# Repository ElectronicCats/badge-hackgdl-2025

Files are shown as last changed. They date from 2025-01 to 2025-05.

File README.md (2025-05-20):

# Badge HackGDL 2025

<p align="center">
    <a href="https://github.com/ElectronicCats/badge-hackgdl-2025/wiki">
        
    </a>
</p>

<p align=center>
    <a href="https://github.com/ElectronicCats/Minino/wiki">
        
    </a>
</p>

Welcome to the official repository of the Hack GDL 2025 event badge, developed by Electronic Cats. This portable device is designed to be interactive, educational, and hackable. It is based on the [Minino](https://github.com/ElectronicCats/Minino) platform, which uses ESP-IDF as the development environment and offers a modular system for creating BLE and Wi-Fi applications.

## Features:
- ESP32-S3
- Bluetooth Low Energy (BLE) + Wi-Fi
- USB-C for power and programming
- 4 x physical buttons for interaction
- 3 neopixel
- Integrated OLED Screen
- 3x AAA Battery Holder
- 1 x Buzzer
- Shitty Addon Connector
- Case
- Based on [Minino](https://github.com/ElectronicCats/Minino), with a modular architecture for multiple apps

## Included Applications:
These applications are ready-to-use and serve as a base for creating your own ideas during the event.
- Bluetooth (BLE) Applications
- Wi-Fi Applications
- Digital Tamagotchi

## Flashing Firmware:
Your badge should come with the latest firmware. If an update is required, this section of the wiki will explain how to flash your badge with the latest firmware. 

### Bootloader mode

To be able to flash your board, you will need to understand how to put it into bootloader mode. You just need to follow the sequence below:

* Press and hold the **BOOT** button
* Press and release the **RST** button
* Release the **BOOT** button

### ESP Tool (Web) update

1. Download the latest firmware from the [releases](https://github.com/ElectronicCats/badge-hackgdl-2025/releases) section.

2. Extract the downloaded file.

3. Open your web browser and go to [ESP Tool](https://espressif.github.io/esptool-js/).

4. Connect your badge to your computer using a USB cable and enter [bootloader mode](https://github.com/ElectronicCats/badge-hackgdl-2025/edit/main/README.md#bootloader-mode). 

5. Once on the page, in the baud rate, select 460800 and click on the “Connect” button.

6. You will see a pop-up window asking you to select the port where your badge is detected. Choose the one labeled “USB JTAG/serial debug unit.”

7. Once your badge is connected, the website will display the “Flash Address” field. Enter 0x0 in that field.

8. Click on “Select File” and look for the files in the unzipped folder. You must match the file and address according to the following table:

| Flash Address | File |
|---|---|
| 0x0 | HackGDL_2025.bin |

9. Once you have all the files, click on “Program.” Wait until the process ends, or you read the message “Leaving...” in the output console.

<p align=center>

</p>

10. When the program is finished, click on the “Disconnect” button.
11. Reset your HackGDL 2025 badge.

### Using the console

>[!IMPORTANT]
> [esptool.py](https://pypi.org/project/esptool/) is required.

To update your badge’s firmware, follow these steps:

1. Download the latest firmware from the [releases](https://github.com/ElectronicCats/badge-hackgdl-2025/releases).

3. Extract the downloaded file.

3. Open a terminal and navigate to the extracted folder. Make sure you see the HackGDL_2025.bin file.

4. Connect your badge to your computer using a USB cable and enter [bootloader mode](https://github.com/ElectronicCats/badge-hackgdl-2025/edit/main/README.md#bootloader-mode). Then check the port it is connected to.
    - **Windows**: Check it in the Device Manager under the Ports section.
    - **Linux**: check it with the `ls /dev/ttyUSB*` or `ls /dev/ttyACM*` command.
    - **macOS**: Check it with the `ls /dev/cu.usb*` command.

5. Run the following command to flash the firmware:

```python
python -m esptool --chip esp32s3 -b 460800 --before default_reset --after hard_reset write_flash --flash_mode dio --flash_size 4MB --flash_freq 80m 0x0 HackGDL_2025.bin
```

## Development Reference:

To compile, modify, or develop new applications for this badge, follow the official [Minino firmware development guide](https://github.com/ElectronicCats/Minino/tree/main/firmware).

> [!NOTE]  
> Although the Minino platform was designed for ESP32-C6, the HackGDL 2025 badge uses an ESP32-S3 as the main microcontroller. Make sure to configure the correct chip target in your development environment.

It includes:
ESP-IDF installation (v5.1.2)
Environment setup
Firmware compilation
Modular app structure
Flash and monitor commands

## FAQs
**Does the badge work out of the box?**

Yes. It comes with functional BLE and WiFi-based apps pre-installed.

**Can I develop my own app?**

Absolutely! Use Minino’s modular system and examples as a starting point.

**Where can I get help?**

Check the Minino wiki or open an issue [here](https://github.com/ElectronicCats/badge-hackgdl-2025/issues).

## Gratitude
Do you want to say thank you? Tag these companies on social networks and show them your badge, thanks to them, it is possible

- [ElectronicCats](https://electroniccats.com/)
- [HackGDL](https://hackgdl.net/)
- [Project TamaLib: A hardware-agnostic first-gen Tamagotchi emulation library](https://github.com/jcrona/tamalib)

## License

<a href="https://github.com/ElectronicCats">
    
</a>

Electronic Cats invests time and resources providing this open source design, please support Electronic Cats and open-source hardware by purchasing products from Electronic Cats!

Designed by Electronic Cats.

Firmware released under an GNU AGPL v3.0 license. See the LICENSE file for more information.

Hardware released under an CERN Open Hardware License v1.2. See the LICENSE_HARDWARE file for more information.

Electronic Cats is a registered trademark, please do not use if you sell these PCBs.

Nov 29 2022

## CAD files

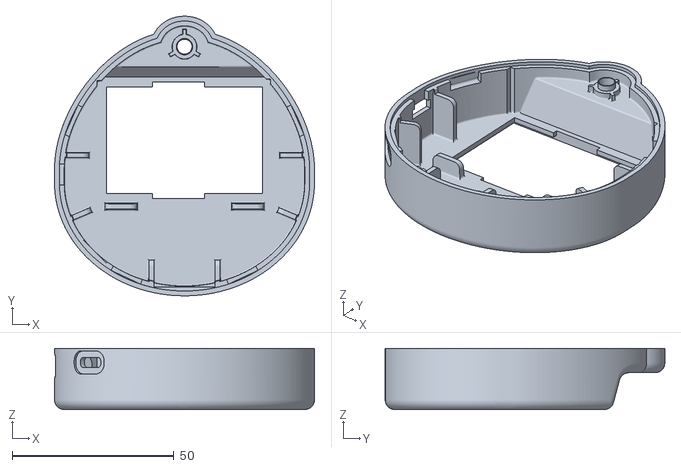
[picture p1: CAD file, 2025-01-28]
case/BOTTOM.stl
80.4 x 86.5 x 18.9

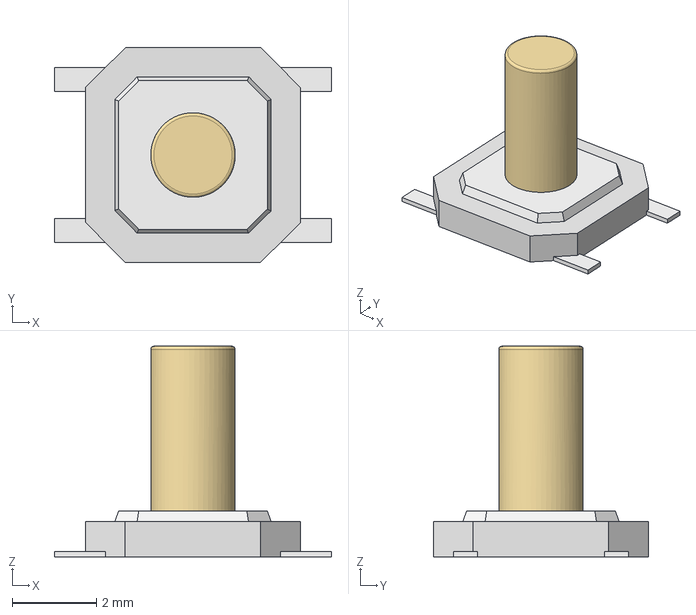
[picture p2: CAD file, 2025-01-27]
hardware/3dmodels/Tactal Switch - SMD (5mmx 5mmx5.0mm).stp
6.58 x 5.10 x 5.00 mm

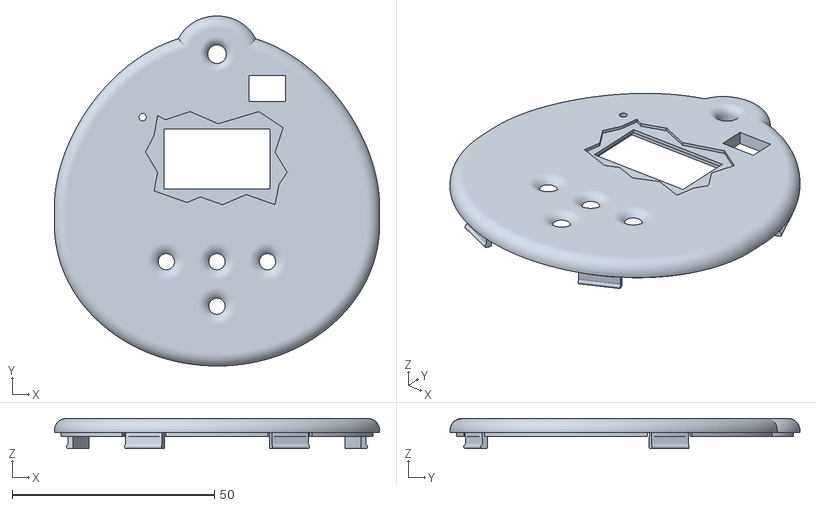
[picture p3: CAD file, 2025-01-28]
case/TOP.stl
80.4 x 86.5 x 7.50

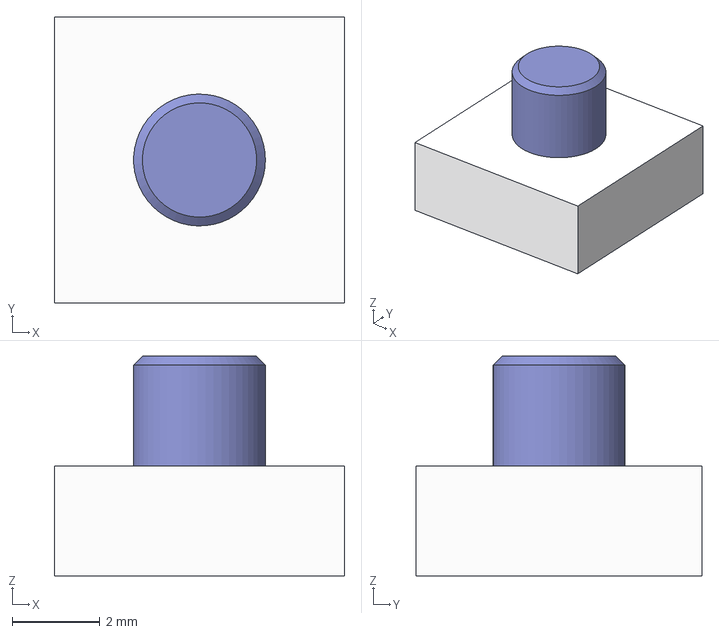
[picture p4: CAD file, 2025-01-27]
hardware/3dmodels/XKB Connection TS-1158UB-C-D-BL.step
6.60 x 6.50 x 5.00 mm

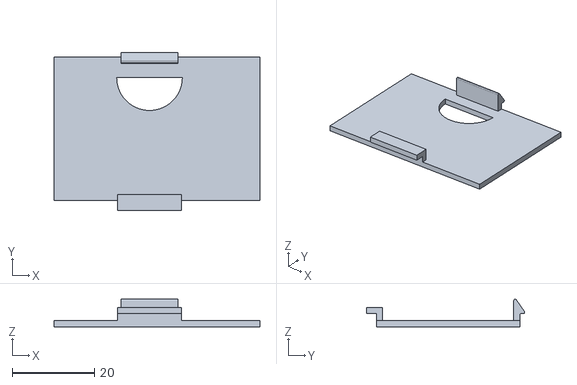
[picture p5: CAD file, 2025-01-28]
case/LID.stl
50.2 x 38.6 x 6.74

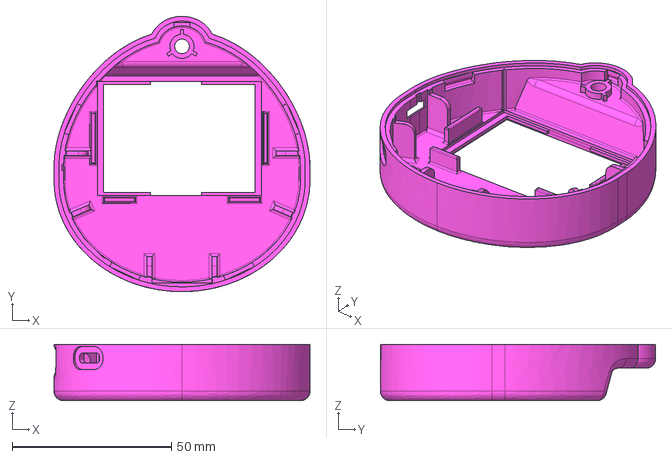
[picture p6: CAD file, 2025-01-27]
hardware/3dmodels/BOTTOM.step
80.4 x 86.5 x 17.7 mm

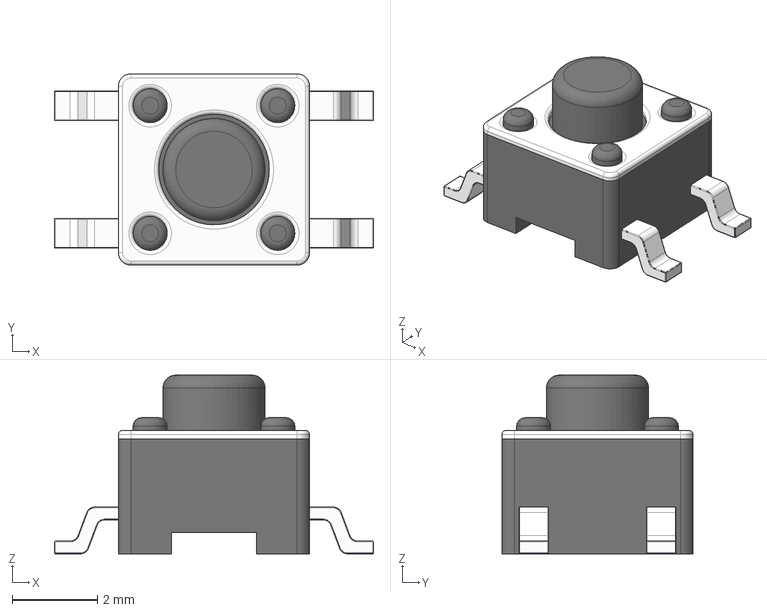
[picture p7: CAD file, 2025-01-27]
hardware/3dmodels/Tact Switch 4.5mm SMT.step
7.50 x 4.50 x 4.20 mm

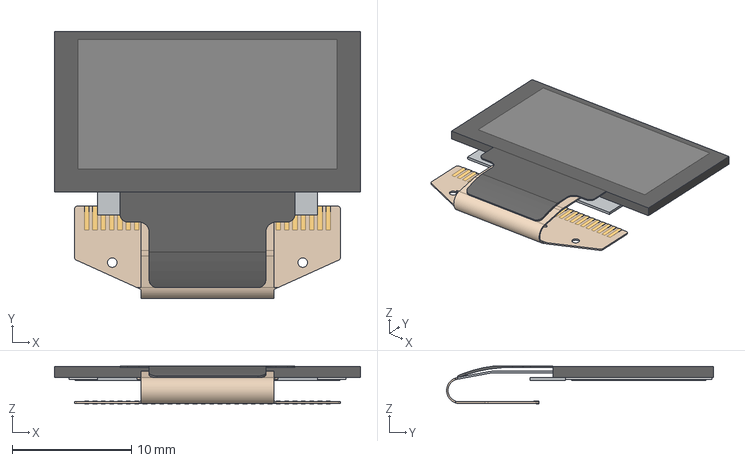
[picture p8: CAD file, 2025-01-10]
hardware/3dmodels/0.96 OLED - Flat Reverse.stp
25.7 x 22.4 x 3.16 mm

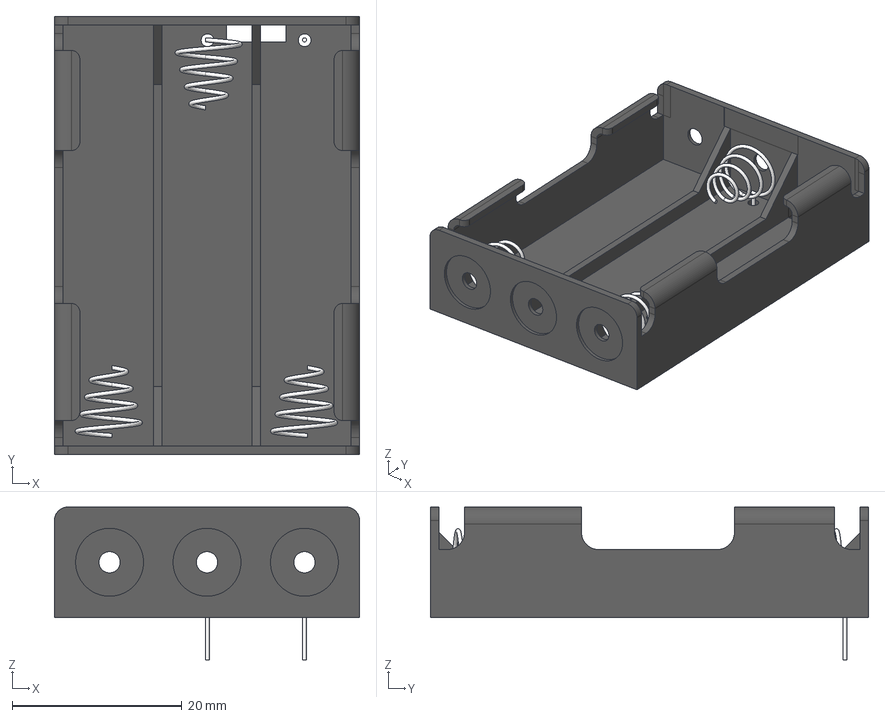
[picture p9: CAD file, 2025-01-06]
hardware/3dmodels/BatteryHolder_3xAAA_THT.step
35.9 x 51.6 x 18.0 mm
Body - Compartment
Body - Spring terminal 1 x 3
Body - Negative connector x 2

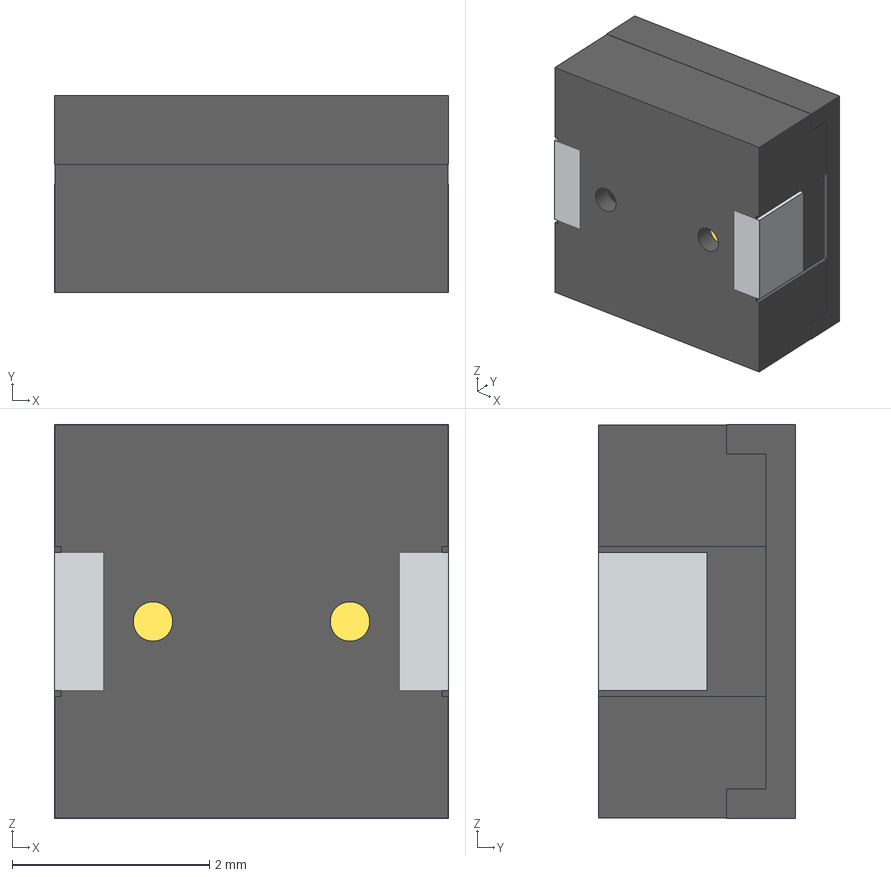
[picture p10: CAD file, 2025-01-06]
hardware/3dmodels/SMT-0440-T-R.step
4.00 x 2.00 x 4.00 mm

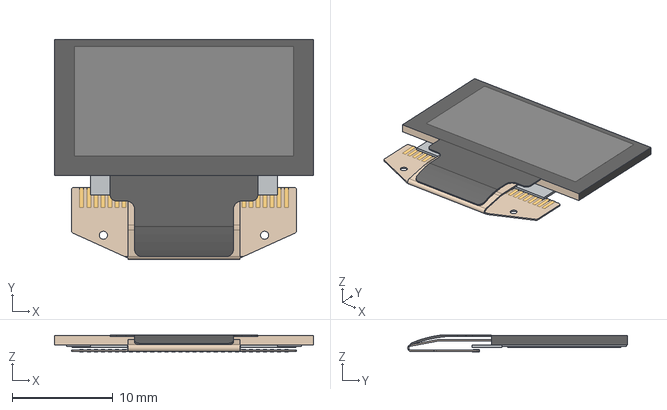
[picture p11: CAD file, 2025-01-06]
hardware/3dmodels/0.96 OLED - Flush.stp
25.7 x 21.8 x 1.66 mm

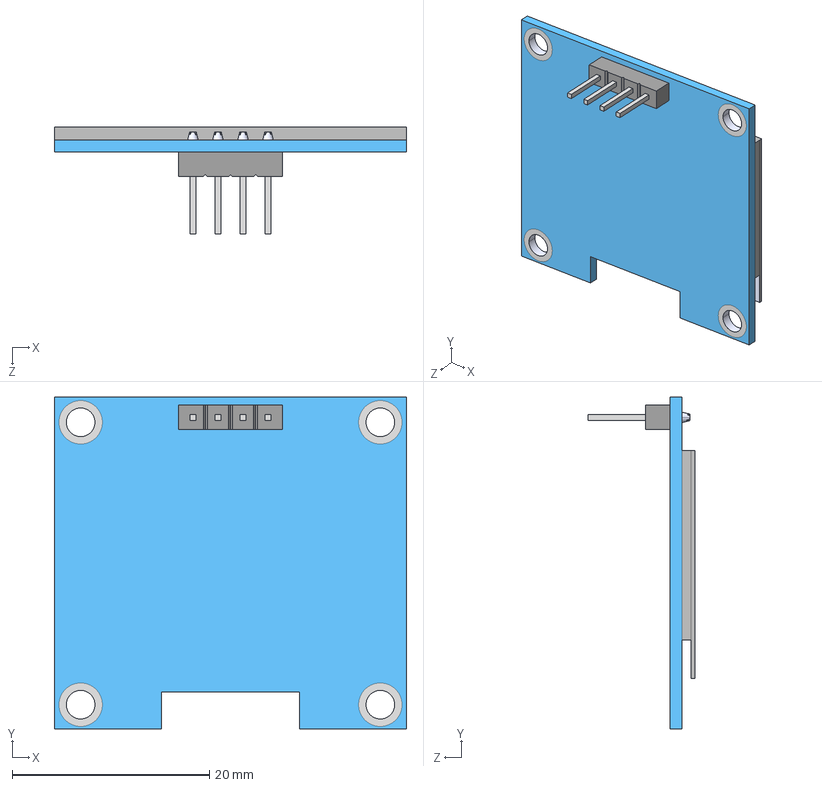
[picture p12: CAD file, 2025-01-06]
hardware/3dmodels/1 3 OLED ICC .STEP
35.7 x 33.6 x 10.8 mm

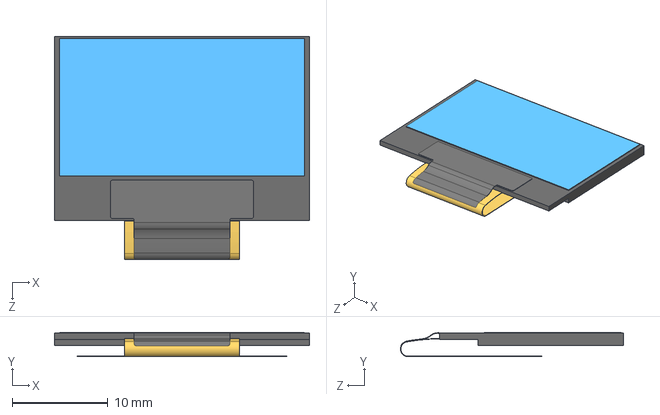
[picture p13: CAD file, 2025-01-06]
hardware/3dmodels/OLED 0.96 inch 64x128.STEP
26.7 x 2.56 x 23.4 mm

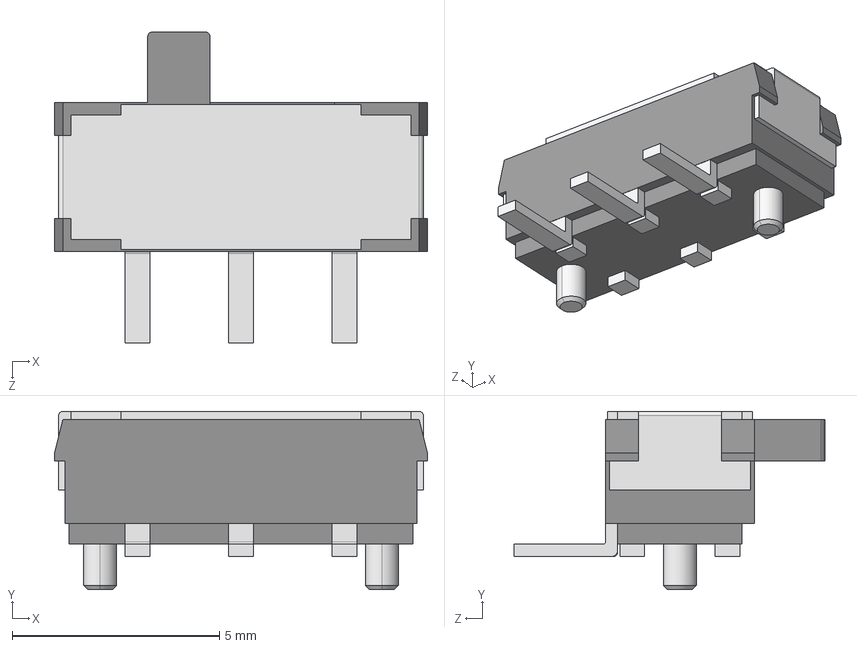
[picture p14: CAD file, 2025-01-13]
hardware/3dmodels/JS102011SAQN.STEP
9.00 x 4.30 x 7.50 mm

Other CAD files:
hardware/3dmodels/buttonv2.step
hardware/3dmodels/TOP.step

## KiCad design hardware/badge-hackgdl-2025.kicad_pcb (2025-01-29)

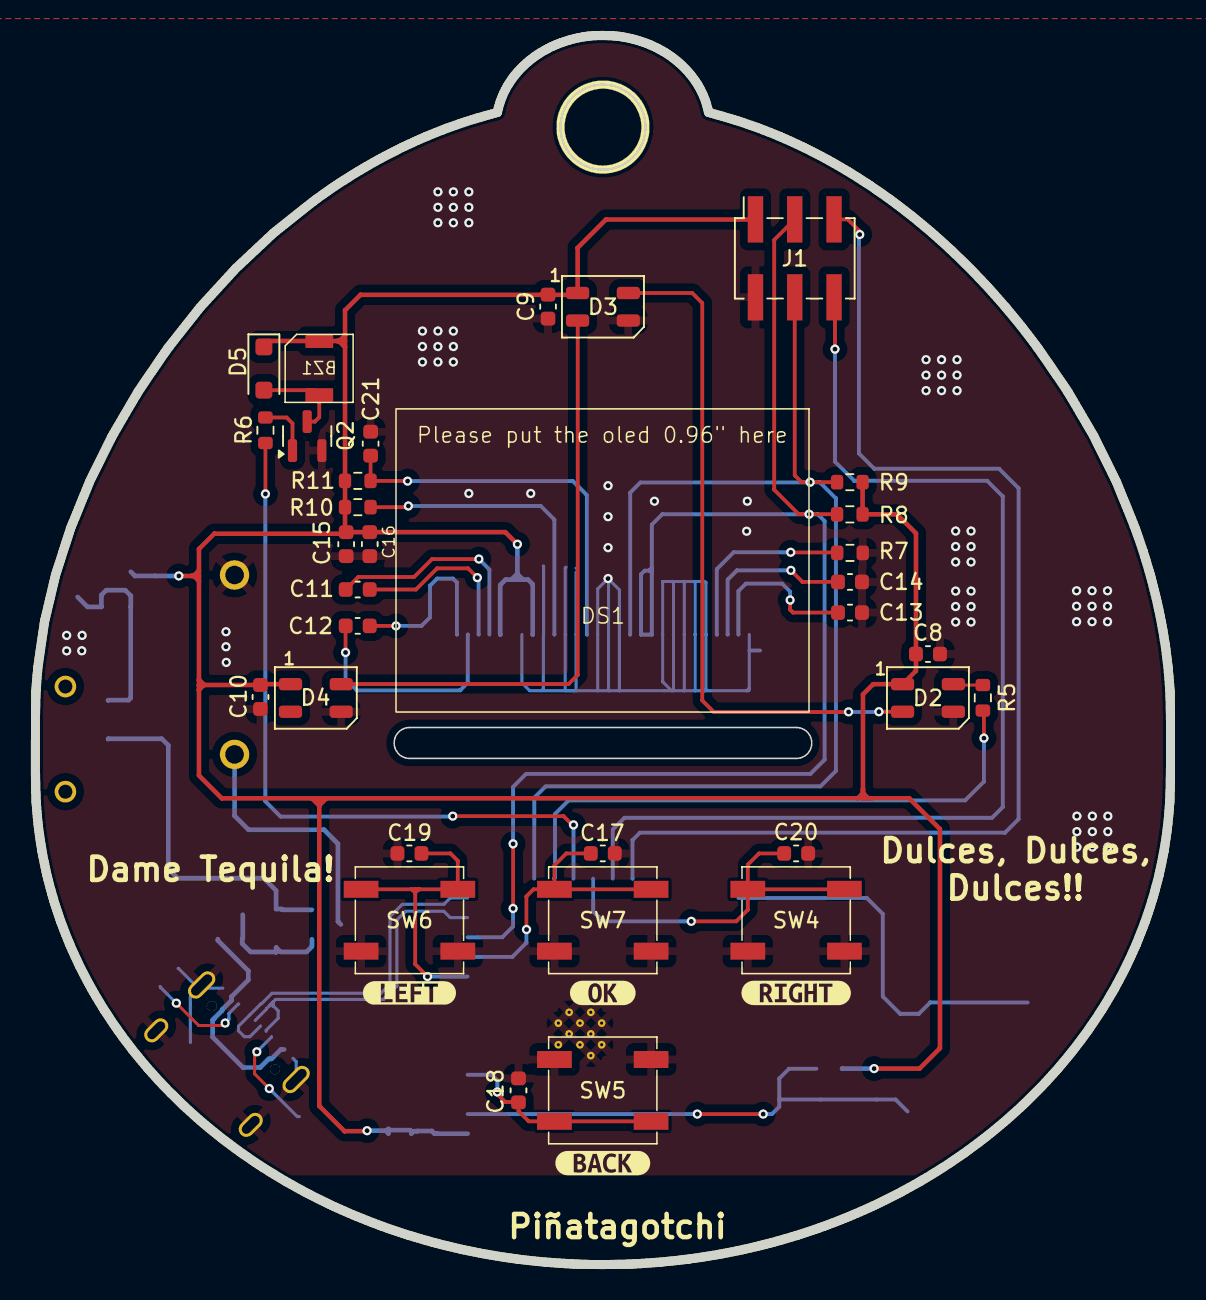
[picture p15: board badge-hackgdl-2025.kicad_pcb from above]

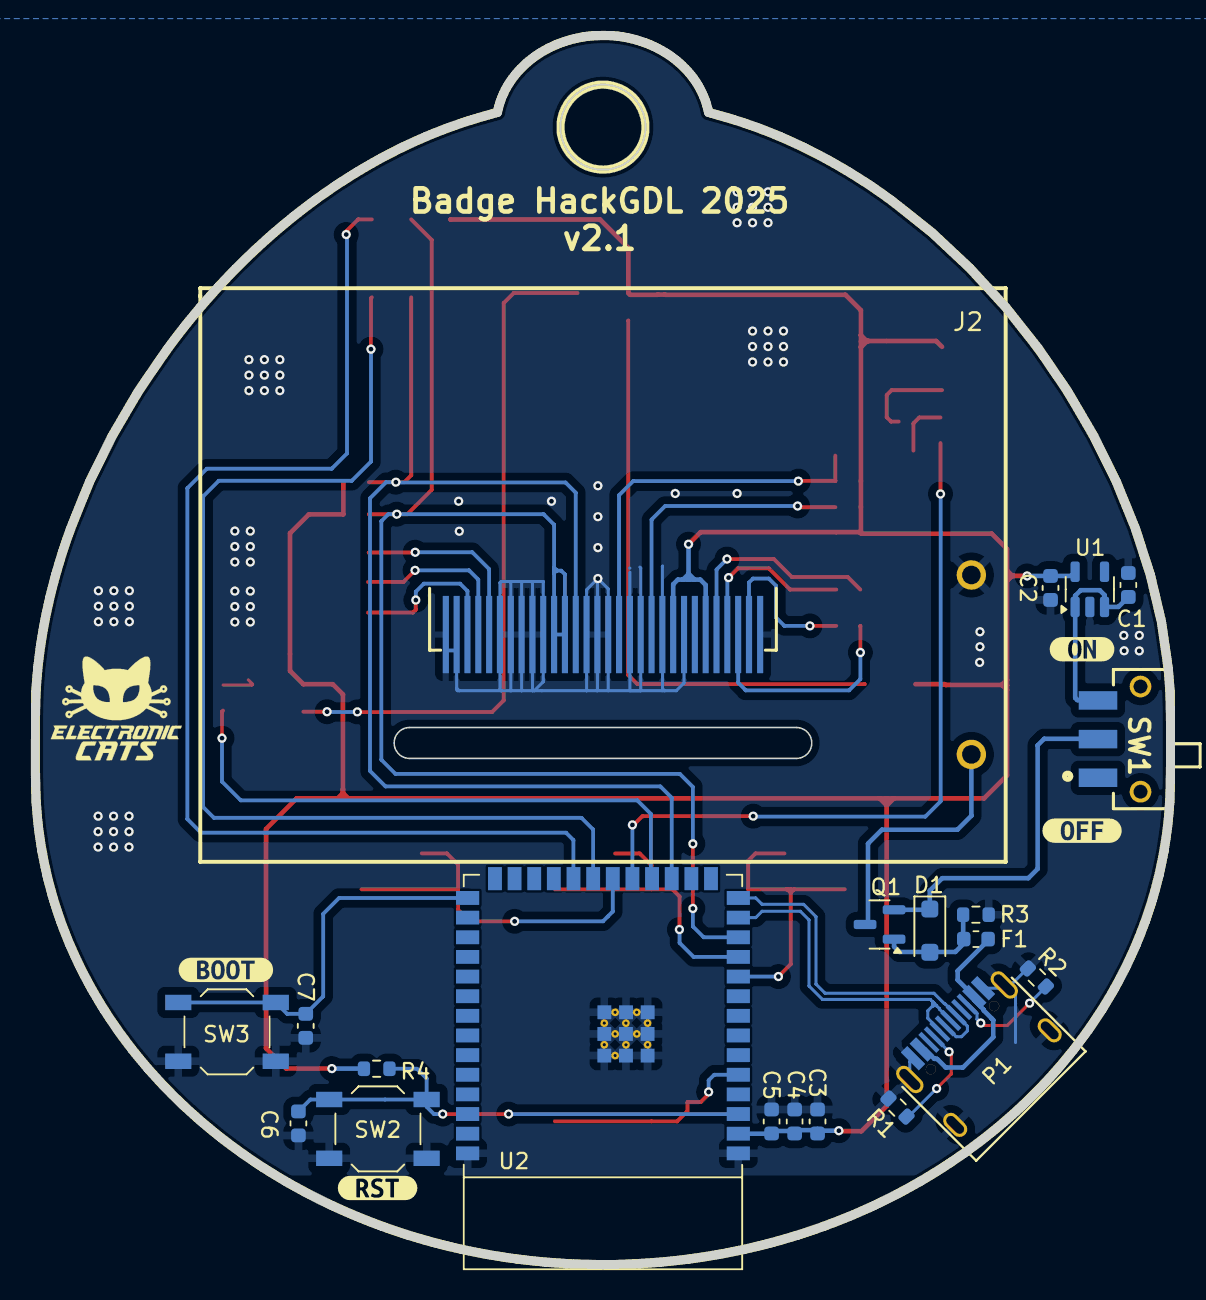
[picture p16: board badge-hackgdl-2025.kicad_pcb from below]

Board: 11 copper layers, 73.4 x 79.5 mm, 64 parts (26 on the bottom side), 37 nets.

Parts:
BZ1: Buzzer; Buzzer4x4
C1, C2, C4, C5, C13, C14, C16: 10uF; C_0603_1608Metric
C3, C11, C12: 1uF; C_0603_1608Metric
C6, C7, C8, C9, C10, C15, C17, C18, C19, C20: 100nF; C_0603_1608Metric
C21: 4.7uF; C_0603_1608Metric
D1, D5: MBR120; D_SOD-123F
D2, D3, D4: WS2812B; LED_WS2812B-Mini_PLCC4_3.5x3.5mm
DS1: OLED-128O064D; ssd1306_oled_conn_through_the_oled
F1: 1A; Fuse_0603_1608Metric
J1: ADDON; PinSocket_2x03_P2.54mm_Vertical_SMD
J2: Battery; BAT-TH_BH-AAA-A1AJ024
P1: USB_C_Plug_USB2.0; C393939
Q1: DMG3415U-7; SOT-23
Q2: MMBT2222A; SOT-23
R1, R2: 5k1; R_0603_1608Metric
R3: 100K; R_0603_1608Metric
R4, R8, R9, R10, R11: 10k; R_0603_1608Metric
R5: 470; R_0603_1608Metric
R6: 1K; R_0603_1608Metric
R7: 390k; R_0603_1608Metric
Ref**: Val**; badge-hackgdl-2025-Edge_Cuts
Ref**#2: Val**; badge-hackgdl-2025-Edge_Cuts
SW1: ON; JS102011SAQN
SW2: RESET; SW_SPST_TL3342
SW3: BOOT; SW_SPST_TL3342
SW4: RIGHT; Button_6.6x6.5
SW5: BACK; Button_6.6x6.5
SW6: LEFT; Button_6.6x6.5
SW7: MIDDLE; Button_6.6x6.5
U1: XC6220B331MR-G; SOT-23-5
U2: ESP32-S3-WROOM-1-N4; ESP32-S3-WROOM-1
kibuzzard-67883A3F: G***; kibuzzard-67883A3F
kibuzzard-67883A4C: G***; kibuzzard-67883A4C
kibuzzard-678830B0: G***; kibuzzard-678830B0
kibuzzard-678830B8: G***; kibuzzard-678830B8
kibuzzard-678830ED: G***; kibuzzard-678830ED
kibuzzard-678830F7: G***; kibuzzard-678830F7
kibuzzard-6789895F: G***; kibuzzard-6789895F
kibuzzard-67898922: G***; kibuzzard-67898922

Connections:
+3V3: BZ1.1 (-), C2.1, C3.1, C4.1, C5.1, C8.2, C9.2, C10.2, C15.1, C16.1, D2.1 (VDD), D3.1 (VDD), D4.1 (VDD), D5.1 (K), DS1.6 (VBAT), DS1.9 (VDD), J1.1, R4.2, R8.2, R9.2, R10.2, R11.2, U1.5 (VOUT), U2.2 (3V3)
+BATT: J2.2, Q1.3 (D)
/BACK: C18.1, SW5.2, U2.5 (IO5)
/BOOT: C7.1, SW3.2, U2.27 (IO0)
/Buzz: R6.1, U2.19 (IO11)
/D+: P1.A6 (D+), U2.14 (IO20)
/D-: P1.A7 (D-), U2.13 (IO19)
/GPIO1: J1.5, U2.22 (IO14)
/GPIO2: J1.6, U2.21 (IO13)
/LEFT: C19.1, SW6.2, U2.10 (IO17)
/MIDDLE: C17.1, SW7.2, U2.11 (IO18)
/NEOPIXEL: R5.1, U2.18 (IO10)
/RIGHT: C20.1, SW4.2, U2.20 (IO12)
/RST: C6.1, R4.1, SW2.2, U2.3 (EN)
/SCL: DS1.18 (D0), J1.4, R9.1, U2.17 (IO9)
/SDA: DS1.19 (D1), DS1.20 (D2), J1.3, R8.1, U2.12 (IO8)
GND: C1.2, C2.2, C3.2, C4.2, C5.2, C6.2, C7.2, C8.1, C9.1, C10.1, C13.1, C14.2, C15.2, C16.2, C17.2, C18.2, C19.2, C20.2, C21.2, D2.3 (VSS), D3.3 (VSS), D4.3 (VSS), DS1.1 (GND), DS1.8 (VSS), DS1.10 (BS0), DS1.12 (BS2), DS1.13 (~CS), DS1.15 (D/~C), DS1.16 (R/~W), DS1.17 (E/~RD), DS1.21 (D3), DS1.22 (D4), DS1.23 (D5), DS1.24 (D6), DS1.25 (D7), DS1.29 (VLSS), DS1.30 (GND), J1.2, J2.1, P1.A1 (GND), P1.S1 (SHIELD), Q2.2 (E), R1.1, R2.1, R3.2, R7.2, SW2.1, SW3.1, SW4.1, SW5.1, SW6.1, SW7.1, U1.2 (GND), U2.1 (GND), U2.40 (GND), U2.41 (GND)
unnamed: BZ1.2 (+), D5.2 (A), Q2.3 (C)
unnamed: D1.1 (K), Q1.2 (S), SW1.2 (B)
unnamed: D2.4 (DIN), R5.2
unnamed: D2.2 (DOUT), D3.4 (DIN)
unnamed: D3.2 (DOUT), D4.4 (DIN)
unnamed: DS1.11 (BS1), R10.1
unnamed: C11.1, DS1.5 (C1N)
unnamed: C11.2, DS1.4 (C1P)
unnamed: C12.2, DS1.2 (C2N)
unnamed: C12.1, DS1.3 (C2P)
unnamed: DS1.26 (IREF), R7.1
unnamed: C13.2, DS1.28 (VCC)
unnamed: C14.1, DS1.27 (VCOMH)
unnamed: C21.1, DS1.14 (~RES), R11.1
unnamed: F1.1, P1.A4 (VBUS)
unnamed: P1.A5 (CC), R1.2
unnamed: P1.B5 (VCONN), R2.2
unnamed: Q2.1 (B), R6.2
unnamed: C1.1, SW1.3 (A), U1.1 (VIN), U1.3 (EN)
VBUS: D1.2 (A), F1.2, Q1.1 (G), R3.1

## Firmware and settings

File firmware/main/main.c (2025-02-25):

#include <stdio.h>

#include "buzzer.h"
#include "cat_console.h"
#include "keyboard_module.h"
#include "menus_module.h"
#include "neopixels_module.h"
#include "oled_screen.h"
#include "preferences.h"

#define PIN_BUZZER CONFIG_GPIO_BUZZER

void app_main(void) {
  buzzer_begin(PIN_BUZZER);
  neopixels_module_begin();
  preferences_begin();
  keyboard_module_begin();
  oled_screen_begin();
  menus_module_begin();
  cat_console_begin(); // Contains a while(true) loop, it must be at the end
}

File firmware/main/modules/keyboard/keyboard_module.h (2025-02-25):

#pragma once

#include "iot_button.h"

#define BACK_BUTTON_PIN CONFIG_GPIO_BACK_BUTTON
#define LEFT_BUTTON_PIN CONFIG_GPIO_LEFT_BUTTON
#define MIDDLE_BUTTON_PIN CONFIG_GPIO_MIDDLE_BUTTON
#define RIGHT_BUTTON_PIN CONFIG_GPIO_RIGHT_BUTTON

#define LEFT_BUTTON_MASK 0b0000 << 4
#define MIDDLE_BUTTON_MASK 0b0001 << 4
#define RIGHT_BUTTON_MASK 0b0010 << 4
#define BACK_BUTTON_MASK 0b0011 << 4

#define BUTTON_ACTIVE_LEVEL 0

/**
 * @brief Enum of the available keyboard buttons
 *
 */
typedef enum {
  BUTTON_LEFT,
  BUTTON_MIDDLE,
  BUTTON_RIGHT,
  BUTTON_BACK,
} keyboard_buttons_layout_t;

/**
 * @brief Struct to hold the button state
 *
 */
typedef struct {
  uint8_t button_pressed;
  uint8_t button_event;
} button_event_state_t;

typedef void (*input_callback_t)(uint8_t, uint8_t);

/**
 * @brief Initialize the keyboard button
 *
 * @param uint32_t button_pin Button pin
 * @param uint8_t mask Mask
 * @param void handler function pointer for the button event callback
 *
 * @return void
 */
void keyboard_module_begin();

void keyboard_module_reset_idle_timer();

void keyboard_module_set_lock(bool lock);

void keyboard_module_set_input_callback(input_callback_t input_cb);

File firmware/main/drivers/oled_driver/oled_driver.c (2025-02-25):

#include <string.h>

#include "esp_log.h"
#include "font8x8_basic.h"
#include "freertos/FreeRTOS.h"
#include "freertos/task.h"
#include "oled_driver.h"

#define PACK8 __attribute__((aligned(__alignof__(uint8_t)), packed))

static const char *TAG = "oled_driver";

static bool encrypt = 0;
static bool typography = 0;

typedef union out_column_t {
  uint32_t u32;
  uint8_t u8[4];
} PACK8 out_column_t;

void oled_driver_init(oled_driver_t *dev, int width, int height) {
#if !defined(CONFIG_OLED_DRIVER_DEBUG)
  esp_log_level_set(TAG, ESP_LOG_NONE);
#endif

  if (dev->_address == SPIAddress) {
    spi_init(dev, width, height);
  } else {
    i2c_init(dev, width, height);
  }
  // Initialize internal buffer
  for (int i = 0; i < dev->_pages; i++) {
    memset(dev->_page[i]._segs, 0, width);
  }
}

int oled_driver_get_width(oled_driver_t *dev) { return dev->_width; }

int oled_driver_get_height(oled_driver_t *dev) { return dev->_height; }

int oled_driver_get_pages(oled_driver_t *dev) { return dev->_pages; }

void oled_driver_show_buffer(oled_driver_t *dev) {
  if (dev->_address == SPIAddress) {
    for (int page = 0; page < dev->_pages; page++) {
      spi_display_image(dev, page, 0, dev->_page[page]._segs, dev->_width);
    }
  } else {
    for (int page = 0; page < dev->_pages; page++) {
      i2c_display_image(dev, page, 0, dev->_page[page]._segs, dev->_width);
    }
  }
}

void oled_driver_set_buffer(oled_driver_t *dev, uint8_t *buffer) {
  int index = 0;
  for (int page = 0; page < dev->_pages; page++) {
    memcpy(&dev->_page[page]._segs, &buffer[index], dev->_width);
    index += dev->_width;
  }
}

void oled_driver_get_buffer(oled_driver_t *dev, uint8_t *buffer) {
  int index = 0;
  for (int page = 0; page < dev->_pages; page++) {
    memcpy(&buffer[index], &dev->_page[page]._segs, dev->_width);
    index += dev->_width;
  }
}

void oled_driver_display_image(oled_driver_t *dev, int page, int seg,
                               uint8_t *images, int width) {
  if (dev->_address == SPIAddress) {
    spi_display_image(dev, page, seg, images, width);
  } else {
    i2c_display_image(dev, page, seg, images, width);
  }
  // Set to internal buffer
  memcpy(&dev->_page[page]._segs[seg], images, width);
}

void oled_driver_display_text(oled_driver_t *dev, int page, char *text, int x,
                              bool invert) {
  if (page >= dev->_pages)
    return;
  int _text_len = strlen(text);
  if (_text_len > 16)
    _text_len = 16;

  uint8_t seg = x;
  uint8_t image[8];
  for (uint8_t i = 0; i < _text_len; i++) {
    memcpy(image, font8x8_basic_tr[(uint8_t)text[i] + encrypt] + typography, 8);
    if (invert)
      oled_driver_invert(image, 8);
    if (dev->_flip)
      oled_driver_flip(image, 8);
    oled_driver_display_image(dev, page, seg, image, 8);
#if 0
		if (dev->_address == SPIAddress) {
			spi_display_image(dev, page, seg, image, 8);
		} else {
			i2c_display_image(dev, page, seg, image, 8);
		}
#endif
    seg = seg + 8;
  }
}

// by Coert Vonk
void oled_driver_display_text_x3(oled_driver_t *dev, int page, char *text,
                                 int text_len, bool invert) {
  if (page >= dev->_pages)
    return;
  int _text_len = text_len;
  if (_text_len > 5)
    _text_len = 5;

  uint8_t seg = 0;

  for (uint8_t nn = 0; nn < _text_len; nn++) {
    uint8_t const *const in_columns = font8x8_basic_tr[(uint8_t)text[nn]];

    // make the character 3x as high
    out_column_t out_columns[8];
    memset(out_columns, 0, sizeof(out_columns));

    for (uint8_t xx = 0; xx < 8; xx++) { // for each column (x-direction)

      uint32_t in_bitmask = 0b1;
      uint32_t out_bitmask = 0b111;

      for (uint8_t yy = 0; yy < 8; yy++) { // for pixel (y-direction)
        if (in_columns[xx] & in_bitmask) {
          out_columns[xx].u32 |= out_bitmask;
        }
        in_bitmask <<= 1;
        out_bitmask <<= 3;
      }
    }

    // render character in 8 column high pieces, making them 3x as wide
    for (uint8_t yy = 0; yy < 3;
         yy++) { // for each group of 8 pixels high (y-direction)

      uint8_t image[24];
      for (uint8_t xx = 0; xx < 8; xx++) { // for each column (x-direction)
        image[xx * 3 + 0] = image[xx * 3 + 1] = image[xx * 3 + 2] =
            out_columns[xx].u8[yy];
      }
      if (invert)
        oled_driver_invert(image, 24);
      if (dev->_flip)
        oled_driver_flip(image, 24);
      if (dev->_address == SPIAddress) {
        spi_display_image(dev, page + yy, seg, image, 24);
      } else {
        i2c_display_image(dev, page + yy, seg, image, 24);
      }
      memcpy(&dev->_page[page + yy]._segs[seg], image, 24);
    }
    seg = seg + 24;
  }
}

void oled_driver_clear_buffer(oled_driver_t *dev) {
  for (int i = 0; i < dev->_pages; i++) {
    memset(dev->_page[i]._segs, 0, dev->_width);
  }
}

void oled_driver_clear_screen(oled_driver_t *dev, bool invert) {
  oled_driver_clear_buffer(dev);
  oled_driver_show_buffer(dev);
}

void oled_driver_clear_line(oled_driver_t *dev, int x, int page, bool invert) {
  // char space[16];
  // memset(space, 0x00, sizeof(space));
  // oled_driver_display_text(dev, page, space, sizeof(space), invert);
  // char* space = "                ";
  char *space = "        ";
  oled_driver_display_text(dev, page, space, x, invert);
}

void oled_driver_contrast(oled_driver_t *dev, int contrast) {
  if (dev->_address == SPIAddress) {
    spi_contrast(dev, contrast);
  } else {
    i2c_contrast(dev, contrast);
  }
}

void oled_driver_software_scroll(oled_driver_t *dev, int start, int end) {
  ESP_LOGD(TAG, "software_scroll start=%d end=%d _pages=%d", start, end,
           dev->_pages);
  if (start < 0 || end < 0) {
    dev->_scEnable = false;
  } else if (start >= dev->_pages || end >= dev->_pages) {
    dev->_scEnable = false;
  } else {
    dev->_scEnable = true;
    dev->_scStart = start;
    dev->_scEnd = end;
    dev->_scDirection = 1;
    if (start > end)
      dev->_scDirection = -1;
  }
}
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

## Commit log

2024-12-27 feat: add kicad project files
    [badge-hackgdl-2025.kicad_pcb, badge-hackgdl-2025.kicad_sch]
2024-12-27 feat(hw): add componnets for usb and microcontroller
    [badge-hackgdl-2025.kicad_sch]
2024-12-27 feat(hw): add neopixels in the schematic
    [badge-hackgdl-2025.kicad_sch]
2024-12-27 feat(hw): add buttons and buzzer
    [badge-hackgdl-2025.kicad_sch]
2024-12-27 feat: add oled connector
    [badge-hackgdl-2025.kicad_sch]
2024-12-30 feat: add components in schematic
    [badge-hackgdl-2025.kicad_pcb, badge-hackgdl-2025.kicad_sch]
2025-01-03 feat: add components
    [board.dxf, clock.dxf, clock_2.dxf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]
2025-01-03 feat(hw): add floor plan
    [badge-hackgdl-2025.kicad_pcb, badge-hackgdl-2025.kicad_sch]
2025-01-06 feat(hw): add 3d models
    [0.96 OLED - Flush.stp, 1 3 OLED ICC .STEP, BatteryHolder_3xAAA_THT.step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]
2025-01-06 feat: add GPIOs shittyaddon connector
    [badge-hackgdl-2025.kicad_sch]
2025-01-07 refactor: port tamagotchi display to mininos screen driver
    [board.dxf, clock.dxf, clock_2.dxf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]
2025-01-08 feat(hw): update bom
    [badge-hackgdl-2025.kicad_sch]
2025-01-08 feat(hw): add 3d model for switch
    [badge-hackgdl-2025.kicad_pcb]
2025-01-08 refactor: improve tamagotchi screen refresh to avoid alliasing
    [oled_driver.c]
2025-01-08 feat(hw): change oled footprint
    [0.96 OLED - Flat Reverse.stp, badge-hackgdl-2025.kicad_pcb]
2025-01-08 feat(hw): move buttons
    [badge-hackgdl-2025.kicad_pcb]
2025-01-09 feat: add wifi apps
    [partitions.csv]
2025-01-10 feat(hw): add routes in pcb
    [badge-hackgdl-2025.kicad_pcb, badge-hackgdl-2025.kicad_sch]
2025-01-13 feat(hw): change ON/OFF switch
    [JS102011SAQN.STEP, badge-hackgdl-2025.kicad_pcb, badge-hackgdl-2025.kicad_sch]
2025-01-14 feat(hw): add labels
    [badge-hackgdl-2025.kicad_pcb, badge-hackgdl-2025.kicad_sch]
2025-01-14 feat(hw): change size of pads in the oled footprint
    [badge-hackgdl-2025.kicad_pcb, badge-hackgdl-2025.kicad_sch]
2025-01-14 feat(hw): change routes in oled
    [badge-hackgdl-2025.kicad_pcb]
2025-01-14 refactor(hw): move buttons
    [badge-hackgdl-2025.kicad_pcb, badge-hackgdl-2025.kicad_sch]
2025-01-15 feat(hw): add space between buttons
    [badge-hackgdl-2025.kicad_pcb, badge-hackgdl-2025.kicad_sch]
2025-01-15 fix(hw): change gpio pins for addon connector
    [badge-hackgdl-2025.kicad_pcb, badge-hackgdl-2025.kicad_sch]
2025-01-15 fix(hw): change left button to gpio 17
    [badge-hackgdl-2025.kicad_pcb, badge-hackgdl-2025.kicad_sch]
2025-01-15 feat(hw): add capacitor in reset pin
    [badge-hackgdl-2025.kicad_pcb, badge-hackgdl-2025.kicad_sch]
2025-01-15 feat(hw): change LDO position
    [badge-hackgdl-2025.kicad_pcb]
2025-01-15 feat(hw): change F1 position
    [badge-hackgdl-2025.kicad_pcb]
2025-01-15 feat(hw): case parts
    [BOTTOM_FINAL.stl, LID_FINAL.stl, TOP_FINAL.stl]
2025-01-16 feat(hw): increase tolerances
    [BOTTOM_FINAL.stl, LID_FINAL.stl, TOP_FINAL.stl]
2025-01-16 feat (hw): increase lid height
    [BOTTOM_FINAL.stl, LID_FINAL.stl, TOP_FINAL.stl]
2025-01-23 feat(hw): update button
    [Tact Switch 4.5mm SMT.step, Tactal Switch - SMD (5mmx 5mmx5.0mm).stp, XKB Connection TS-1158UB-C-D-BL.step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]
2025-01-23 feat(hw): change components in BOM
    [badge-hackgdl-2025.kicad_pcb, badge-hackgdl-2025.kicad_sch]
2025-01-23 feat(hw): add 3d model for pcb
    [BOTTOM.step, TOP.step, badge-hackgdl-2025.kicad_pcb]
2025-01-23 feat: add animations module thread safe
2025-01-27 refactor(hw): change routes width
    [badge-hackgdl-2025.kicad_pcb]
2025-01-27 feat(hw): new buttons case design
    [BOTTOM.stl, BOTTOM_FINAL.stl, LID.stl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]
2025-01-28 refactor(hw): switch approached the edge of the pcb
    [badge-hackgdl-2025.kicad_pcb, badge-hackgdl-2025.kicad_sch]
2025-01-28 feat: add esp32c6 support
2025-01-29 fix(hw): add GND path and change the oled footprint side
    [badge-hackgdl-2025.kicad_pcb]
2025-01-29 fix: buzzer stack overflow & update credits
    [buzzer.c]
2025-01-31 feat: increase flash file system partition space
    [partitions.csv]
2025-02-20 fix: avoid playing buzzer with null freq
    [buzzer.c]
2025-02-25 refactor: set esp32S3 on make file
2025-05-09 fix: back button ok in local file manager
